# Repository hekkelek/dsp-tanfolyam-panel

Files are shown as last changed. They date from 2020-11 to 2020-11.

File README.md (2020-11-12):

# dsp-tanfolyam-panel
Originally intended for teaching audio signal processing in 2014, this is a simple, Arduino-compatible development board using an STM32F405 microcontroller. It might not be my best design, but it works. Its form factor resembles the Arduino Uno, but it's a bit longer to give space to the audio codec.

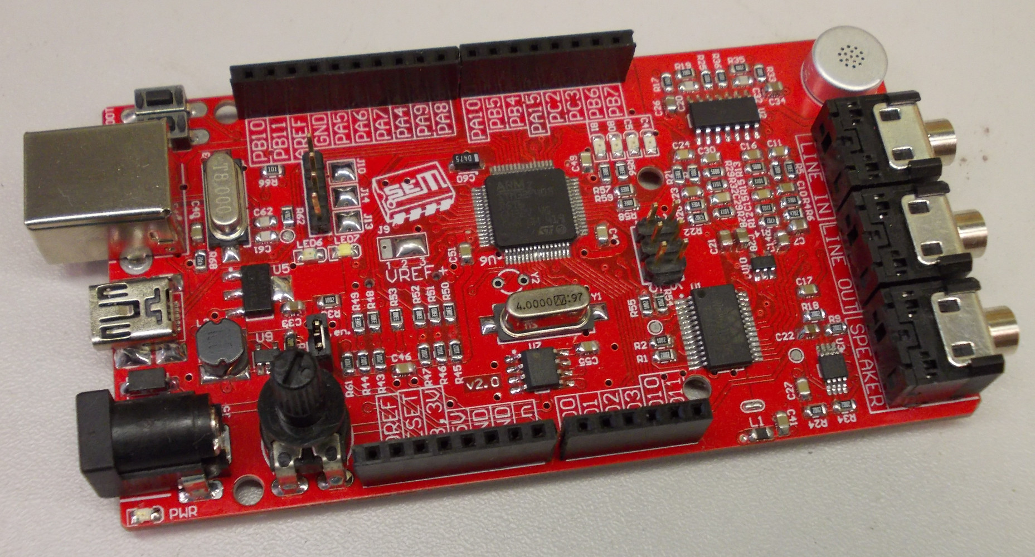
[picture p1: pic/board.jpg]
The hardware


## Features
- STM32F405RGT6 LQFP-64 microcontroller,
- Integrated ST-Link v2,
- USB bootloader can be used too,
- WM8591 24-bit I2S audio codec,
- TS486 headphone amplifier,
- Integrated microphone,
- SD card,
- 4 integrated LEDs,
- I2C EEPROM,
- Potentiometer (can be disconnected if not needed),
- Arduino form factor.

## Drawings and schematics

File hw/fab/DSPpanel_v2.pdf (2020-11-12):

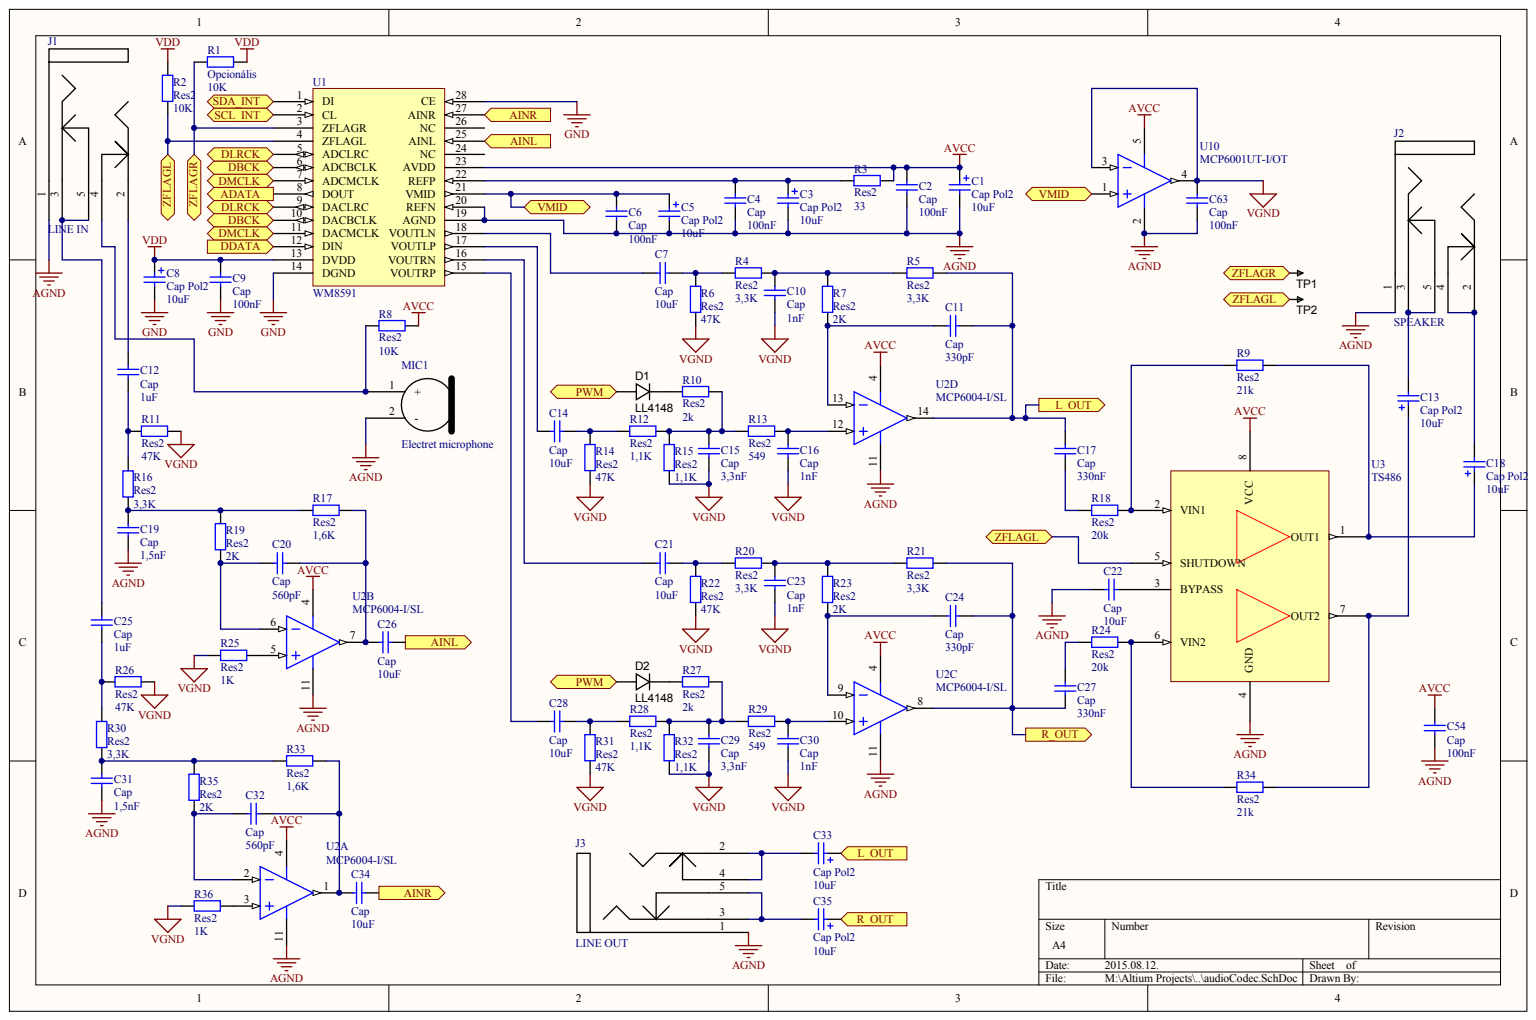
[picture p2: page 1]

CL 2 | AINL
ZFLAGR 3 | GND
ZFLAGL 4

PWM C14 | C11 Cap

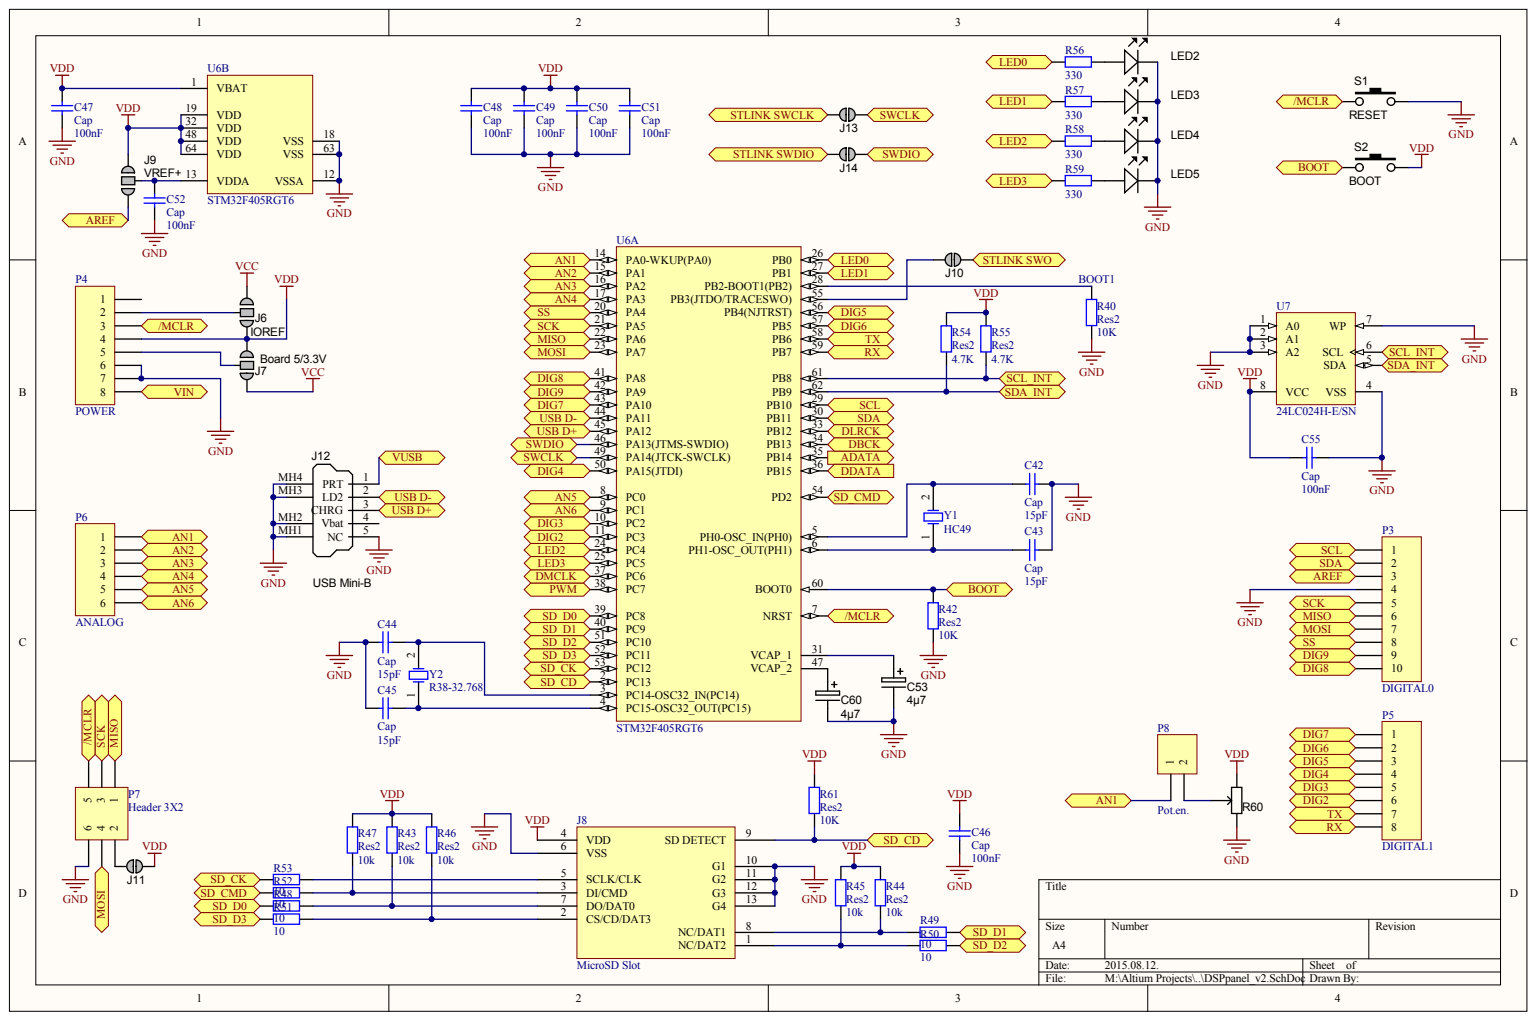
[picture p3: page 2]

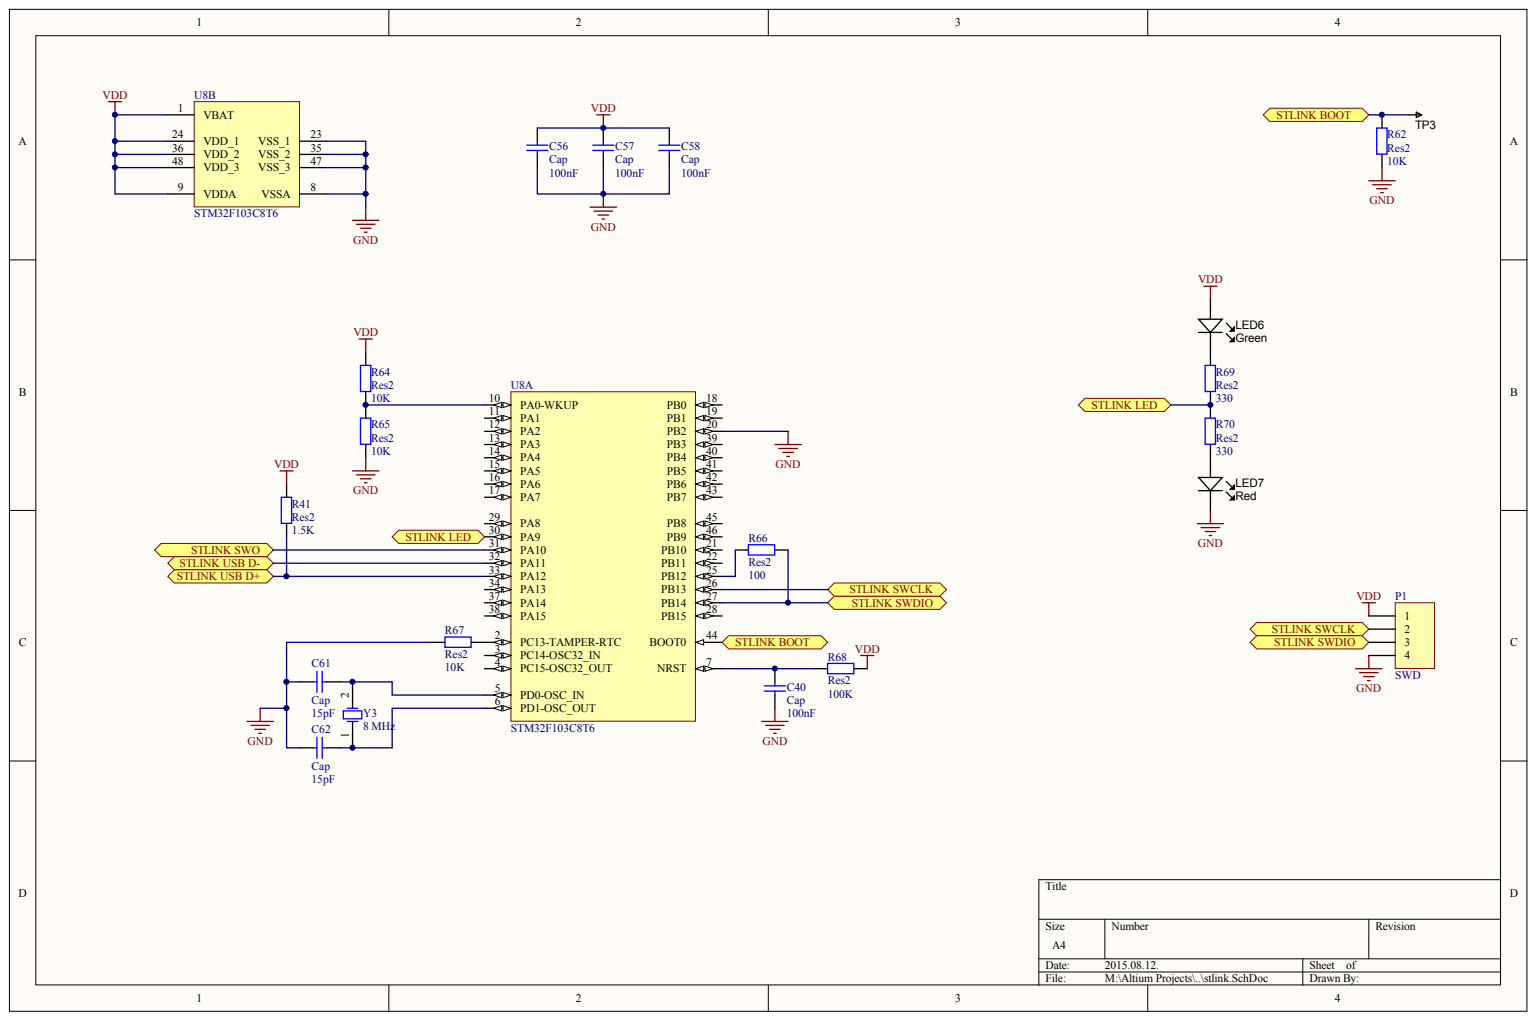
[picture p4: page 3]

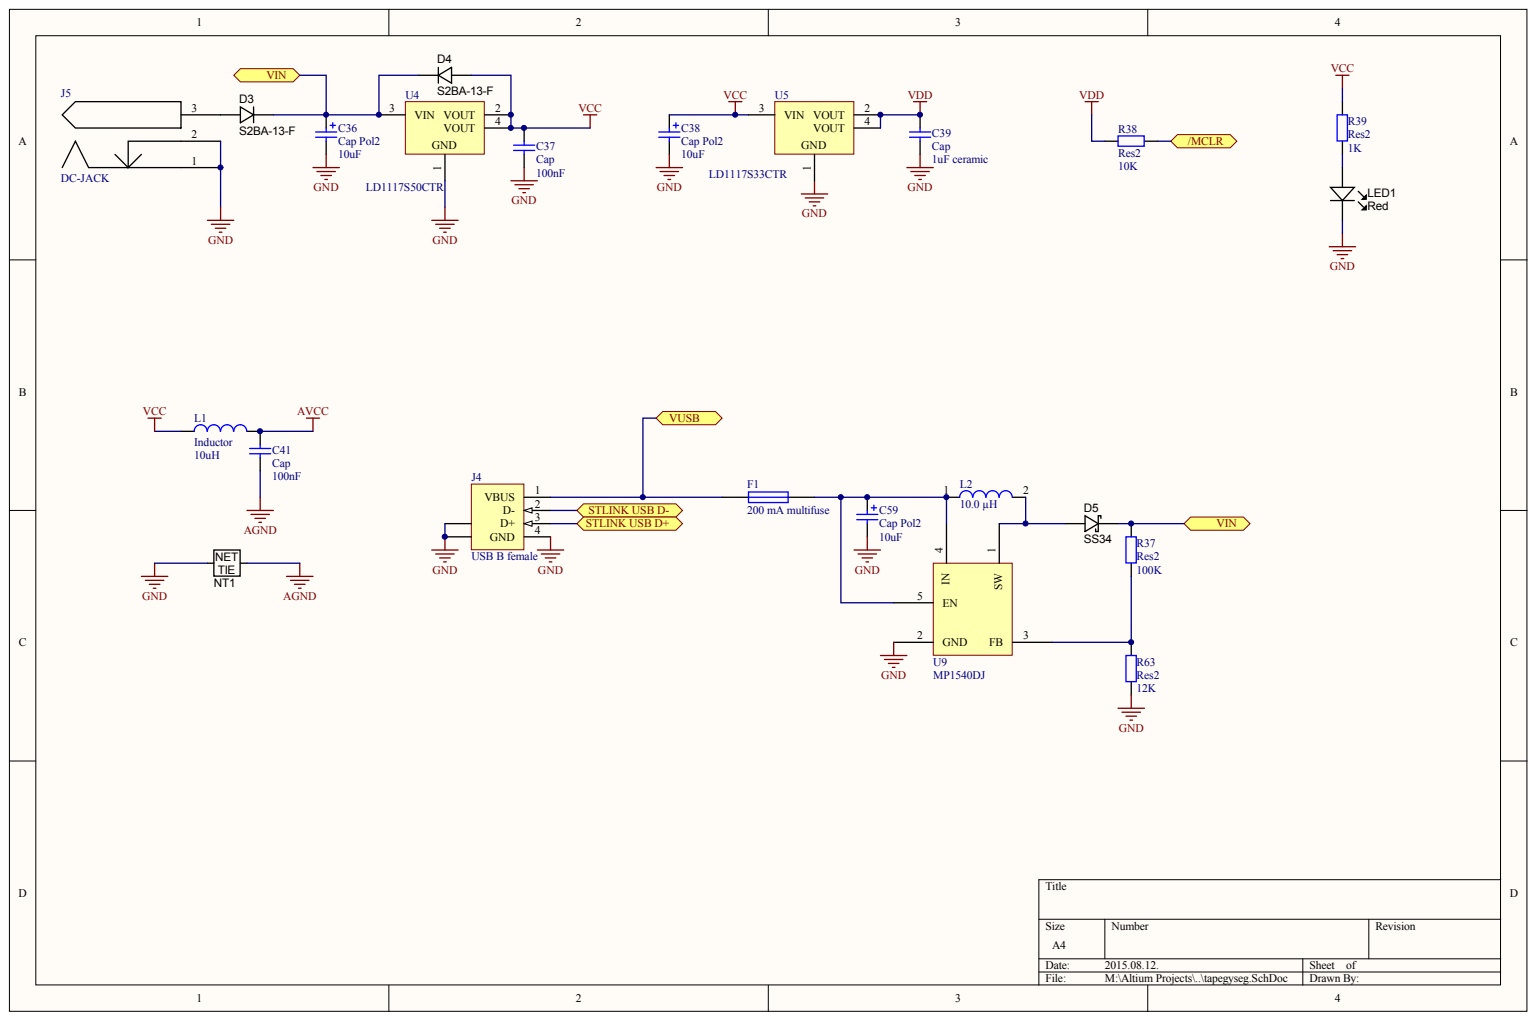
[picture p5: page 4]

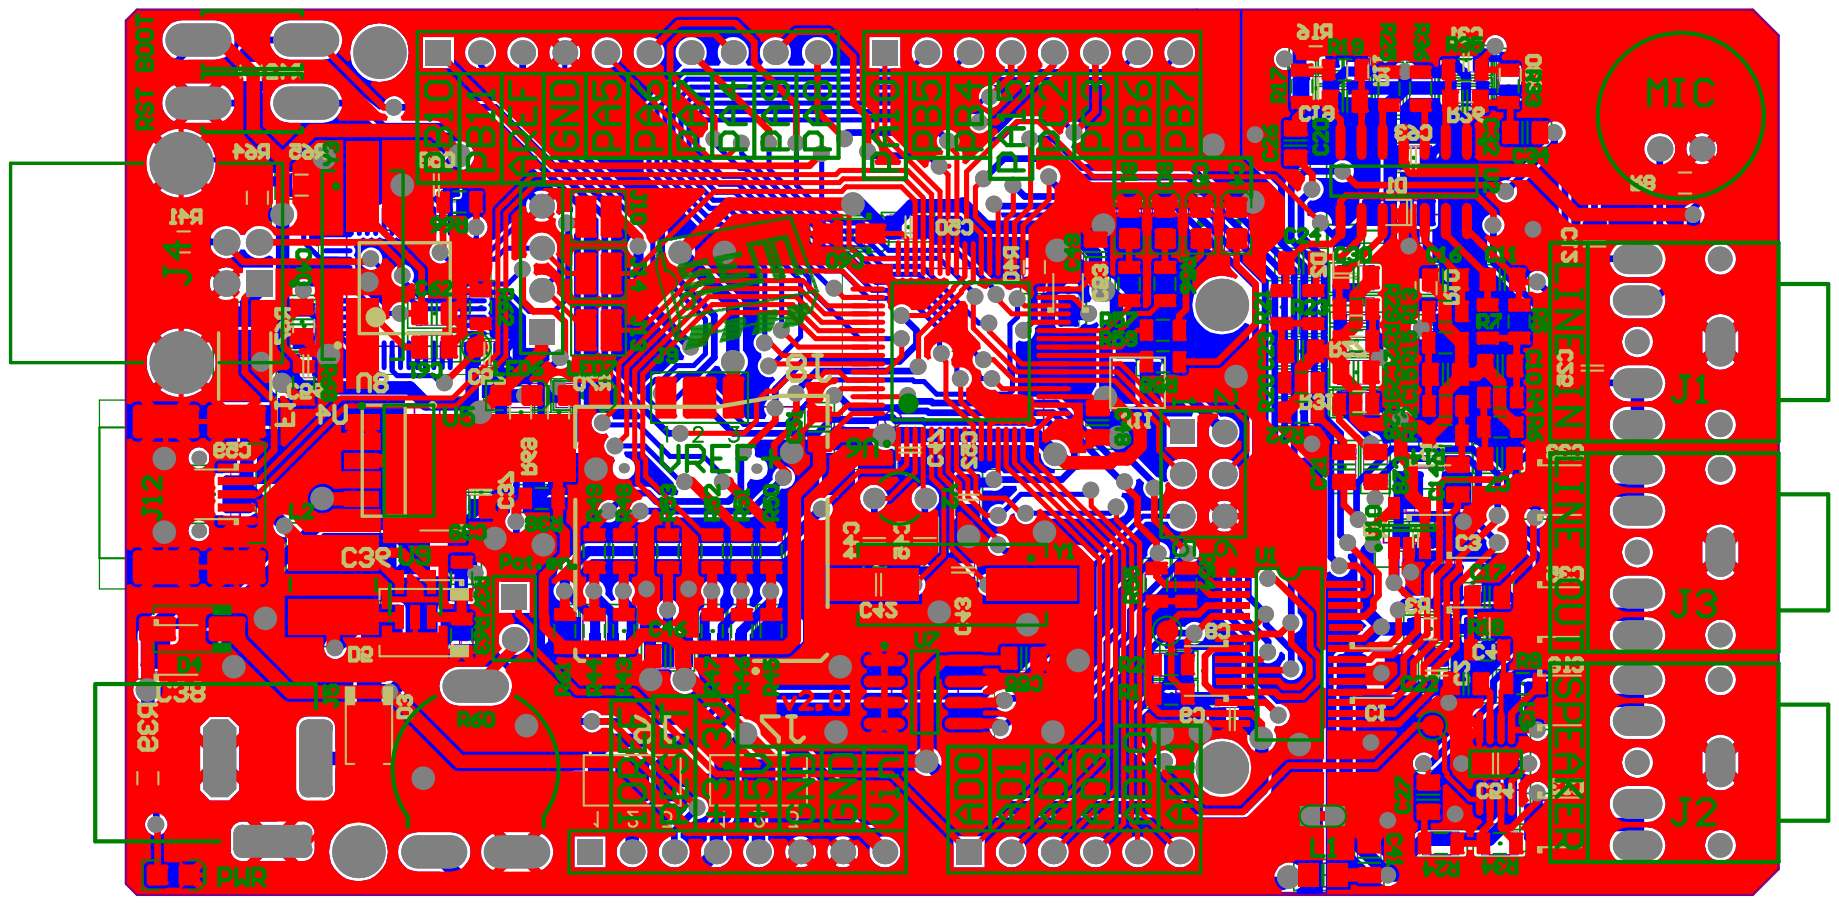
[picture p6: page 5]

Part List | <Parameter Title not found>
Source Data From: | DSPpanel_v2.PrjPcb
Project: | | DSPpanel_v2.PrjPcb
Variant: | | None
Report Date: 2015.08.12. | 9:45:32
Print Date: | 12-Aug-15 | 9:45:41 AM
Designator | Comment | #Column Name Error:LibRFo otprint | | Description
C1, C3, C5, C8, C13, C18, C33, C35, C36, C38, C59 | Cap Pol2 | | CAPMP3528X210N | Polarized Capacitor (Axial)
C2, C4, C6, C7, C9, C10, C11, C12, C14, C15, C16, C17, C19, C20, C21, C22, C23, C24, C25, C26, C27, C28, C29, C30, C31, C32, C34, C37, C39, C40, C41, C42, C43, C44, C45, C46, C47, C48, C49, C50, C51, C52, C54, C55, C56, C57, C58, C61, C62, C63 | Cap | | CAPC2012X135N | Capacitor
C53, C60 | 4µ7 | | CAPMP3216X180N | Capacitor SMD Tantalum 4.7uF 10% 16V 3216-18
D1, D2 | Mini MELF | | SOD80, LL-34 | Diode SMD 100V 150mA 500mW SOD80
D3, D4 | 100V; 1.5A | | DO-214AC | Diode SMD 100V 1.5A SMA
D5 | SS34 | | DO-214AA | Diode Schottky SMD 30V 2A DO-214AA
F1 | 200 mA multifuse | | RESC6332X70N | Fuse
J1 | LINE IN | | STEREO JACK 3.5 mm | Sztereo audio csatlakozó 3,5 mm
J2 | SPEAKER | | STEREO JACK 3.5 mm | Sztereo audio csatlakozó 3,5 mm
J3 | LINE OUT | | STEREO JACK 3.5 mm | Sztereo audio csatlakozó 3,5 mm
J4 | USB B female | | 1437106 | USB 1.1, Right Angle, Thru-Hole, B Type, Receptacle, 4 Position, Natural
J5 | DC-JACK | | JACK | Tápcsatlakozó
J8 | MicroSD Slot | | MICROSD Slot
J12 | USB Mini-B | | USB_Mini-B_Molex_SMT | Connector SMD USB Type Mini-B
L1 | Inductor | | 6-0805_N | Inductor
L2 | 7447745100 | | WE-PD2-MS | SMD Pow er Inductor WE-PD2, L = 10.0 µH
LED1 | Red | | LED-0805-K | LED 0805 SMD Red 6mcd 621nm
LED2, LED6, LED7 | B0 | | LED-0805-K | LED 0805 SMD Red 6mcd 621nm
LED3 | B1 | | LED-0805-K | LED 0805 SMD Red 6mcd 621nm
LED4 | C4 | | LED-0805-K | LED 0805 SMD Red 6mcd 621nm
LED5 | C5 | | LED-0805-K | LED 0805 SMD Red 6mcd 621nm
MIC1 | Electret microphone | | MIC 10 mm | Elektret mikrofon kapszula
P1 | SWD | | HDR1X4 | Header, 4-Pin
P3 | DIGITAL0 | | HDR1X10 | Header, 10-Pin
P4 | POWER | | HDR1X8 | Header, 8-Pin
P5 | DIGITAL1 | | HDR1X8 | Header, 8-Pin
P6 | ANALOG | | HDR1X6 | Header, 6-Pin
P7 | Header 3X2 | | HDR2X3 | Header, 3-Pin, Dual row
P8 | Pot.en. | | HDR1X2 | Header, 2-Pin
R1 | Opcionális | | RESC2012X70N | Resistor
R2, R3, R4, R5, R6, R7, R8, R9, R10, R11, R12, R13, R14, R15, R16, R17, R18, R19, R20, R21, R22, R23, R24, R25, R26, R27, R28, R29, R30, R31, R32, R33, R34, R35, R36, R37, R38, R39, R40, R41, R42, R43, R44, R45, R46, R47, R48, R49, R50, R51, R52, R53, R54, R55, R56, R57, R58, R59, R61, R62, R63, R64, R65, R66, R67, R68, R69, R70 | Res2 | | RESC2012X70N | Resistor
R60 | 25 turns | | PT-105 | Trimmer THD
S1 | RESET | | TACT6x3 | Sw itch, tact, 5.0mm stem
S2 | BOOT | | TACT6x3 | Sw itch, tact, 5.0mm stem
U1 | WM8591 | | SSOP-28 | WM8591 AUDIO CODEC
U2 | MCP6004-I/SL | | SOIC-SL14_N | 1 MHz, Low -Pow er Operational Amplifier, 14-Pin SOIC, Industrial Temperature
U3 | TS486 | | MSOP-MS8_M | 0.1 W audio amplifier
U4 | LD1117S50CTR | | SOT-223_M | Fixed Low Drop Positive Voltage Regulator, 5V, 4-Pin SOT-223, Tape and Reel
U5 | LD1117S33CTR | | SOT-223_L | Fixed Low Drop Positive Voltage Regulator, 3.3V, 4-Pin SOT-223, Tape and Reel
U6 | STM32F405RGT6 | | STM-LQFP64_M | ARM Cortex-M4 32-bit MCU+FPU, 210 DMIPS, 1024 kB Flash, 192 kB Internal RAM, 51 I/Os, 64-pin LQFP, -40 to 85 degC, Tray
U7 | 24LC024H-E/SN | | SOIC-SN8_M | 2Kbit, 1MHz, 2.5V, Addressable Serial EEPROM, 8-Pin SOIC 150mil, Extended Temperature
U8 | STM32F103C8T6 | | STM-LQFP48_N | ARM Cortex-M3 32-bit MCU, 64 KB Flash, 20 KB Internal RAM, 37 I/Os, 48-pin LQFP, -40 to 85 degC, Tray
U9 | MP1540DJ | | S5 | Step-up converter
U10 | MCP6001UT-I/OT | | SOT-23-OT5_M | 1 MHz, Low -Pow er Operational Amplifier, 5-Pin SOT-23, Industrial Temperature, Tape and Reel
Y1 | HC49 | | HC49/4H_SMX | Surface Mount Quartz Crystal
Y2 | R38-32.768 | | R38 | Tuning Fork Crystal Unit
Y3 | 8 MHz | | HC49/4H_SMX | Surface Mount Quartz Crystal
